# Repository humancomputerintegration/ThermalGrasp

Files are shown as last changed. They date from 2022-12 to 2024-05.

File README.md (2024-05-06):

<p align="center">

![Figure 1 has two photos labelled (a) and (b). Figure 1(a) depicts a user kneeling with their rear knee on artificial turf and their front foot on top of sand. They are wearing thermal feedback devices on their hands and feet, as well as a VR headset. The foot that is in the sand is experiencing cold sensation. One of their hands is holding a wooden dowel rod and is experiencing heat from a fire shown in VR. Figure 1(b) depicts a fabricated device that wraps around the user's hand.](/Images/Fig-01-Large.jpg?raw=true)

</p>

# ThermalGrasp

This is a repository for the prototype ThermalGrasp devices created by Alex Mazursky, Jas Brooks, Beza Desta, and Pedro Lopes at the University of Chicago's [Human Computer Integration Lab](https://lab.plopes.org/). Our wearable thermal interfaces made with the ThermalGrasp approach enable users to grab and walk on real objects with minimal obstruction. For specific study details, please refer to our paper.
## Repository Structure

* `Arduino` contains code for the microcontroller (Arduino Mega).
* `3D-prints` contains models for the form-fitting shells for the hands and feet (.stl files). These can be printed in regular PLA using an FDM 3D printer. Additionally includes Fusion360 assemblies (.f3d files) of the entire device (shells, peltiers, fans, copper, etc.).

## Hardware

<p align="center">

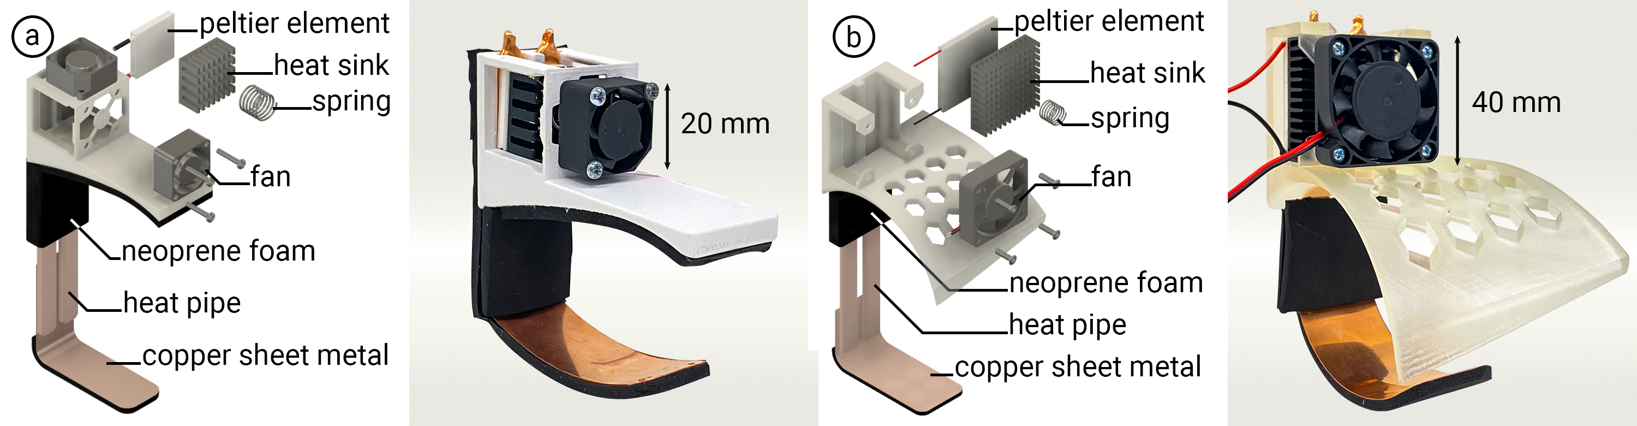
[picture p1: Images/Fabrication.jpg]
Shows our hand and footworn devices. A rendering of the components labeled in an exploded view is depicted, next to an image of the fabricated device.


</p>

Here are the specific hardware components used in each device instantiation and our hardware used in Study 2's backpack.

- Peltiers (foot: TEC12706, hand: CP60231H)
- Copper heat pipes (foot: 70W 11.2 x 3.5 x 100mm, hand: 60W 8.3 x 2.5 x 70mm)
- Copper sheet metal (0.2mm thick)
- Neoprene foam (3.2mm thick, easily compressible)
- Heatsinks (foot: 40 x 40 x 12mm, hand: 20 x 20 x 10mm)
- Fans (foot: 24V, 40 x 40mm, hand: 12V, 20 x 20mm)
- Temperature sensors (100kΩ NTC 3950 thermistors) 
- Motor drivers (VNH3SP30)
- Microcontroller (ATmega2560/Arduino Mega)
- MOSFET (RFP30N06LE, triggers fans)

## Citing

When using or building upon this device in an academic publication, please consider citing as follows:

A. Mazursky, J. Brooks, B. Desta and P. Lopes, "ThermalGrasp: Enabling Thermal Feedback even while Grasping and Walking," in 2024 IEEE Conference Virtual Reality and 3D User Interfaces (VR), Orlando, FL, USA, 2024 pp. 342-353.
doi: 10.1109/VR58804.2024.00056

## Contact

For any questions about this repository, please contact alexmazursky@uchicago.edu

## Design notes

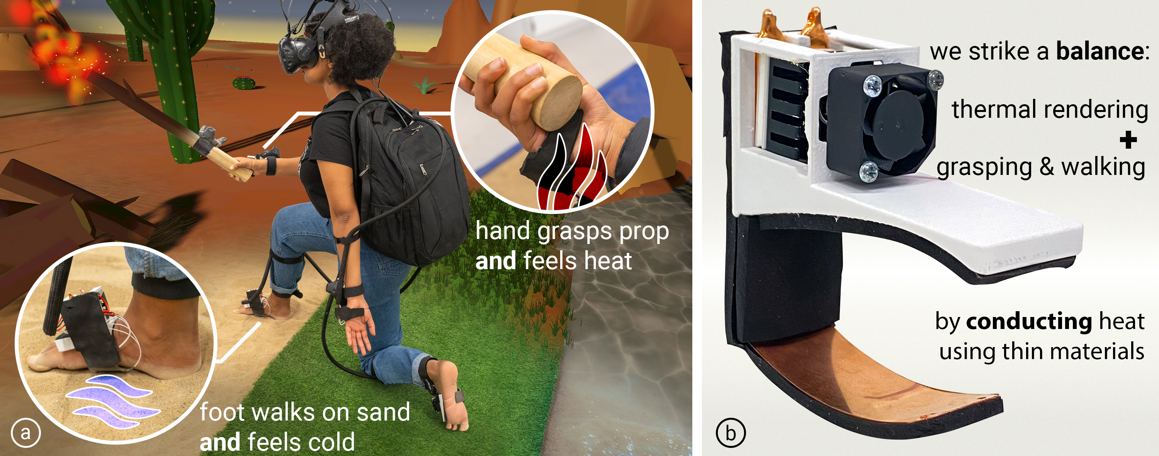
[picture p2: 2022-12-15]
Images/Fig-01-Large.jpg

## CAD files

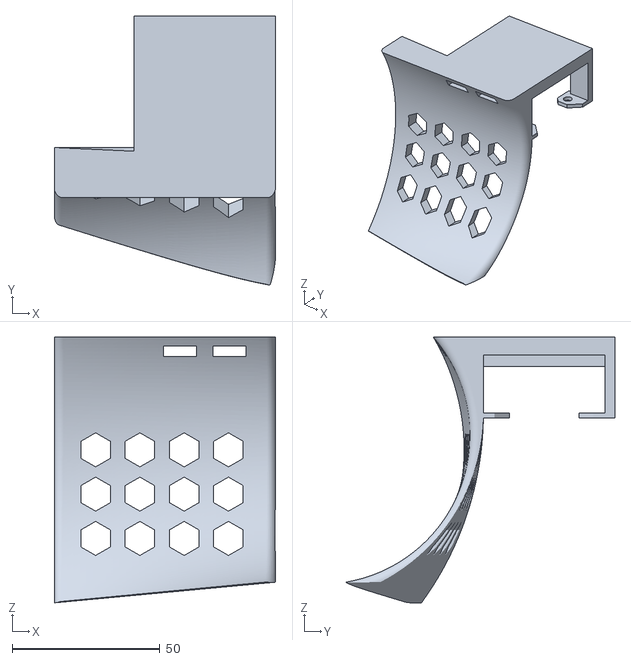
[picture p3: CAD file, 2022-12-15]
3D-prints/shell-foot.stl
75.0 x 91.1 x 90.0

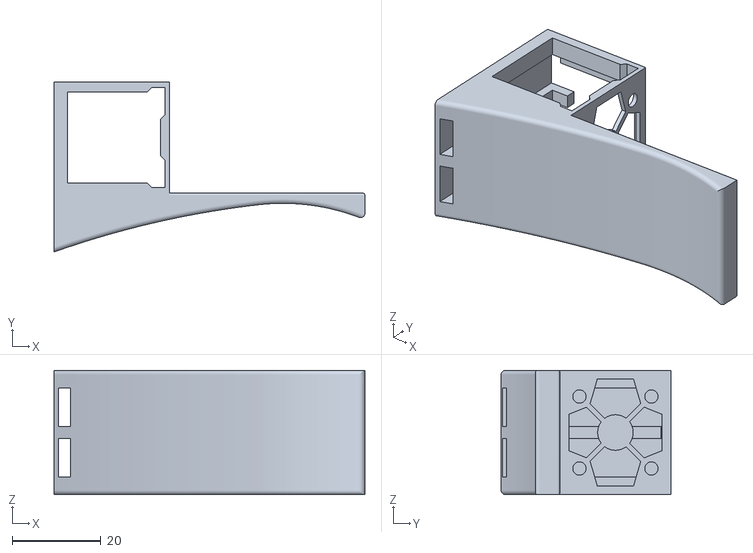
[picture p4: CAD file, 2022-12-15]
3D-prints/shell-hand.stl
70.0 x 38.2 x 28.0

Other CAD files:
3D-prints/ThermalGrasp-hand-assembly.f3d

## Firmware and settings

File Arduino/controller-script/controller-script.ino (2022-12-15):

bool debug = true;

/////////////
// sensing //
/////////////
// which analog pin to connect
#define THERMISTORPIN1 A0
#define THERMISTORPIN2 A1
#define THERMISTORPIN3 A3
#define THERMISTORPIN4 A2 // bug fix due to soldering error
#define THERMISTORPIN5 A4
#define THERMISTORPIN6 A5
#define THERMISTORPIN7 A6
#define THERMISTORPIN8 A7

// resistance at 25 degrees C
#define THERMISTORNOMINAL 100000
// temp. for nominal resistance (almost always 25 C)
#define TEMPERATURENOMINAL 25
// how many samples to take and average, more takes longer
// but is more 'smooth
#define NUMSAMPLES 25
// The beta coefficient of the thermistor (usually 3000-4000)
#define BCOEFFICIENT 3950
// the value of the 'other' resistor
#define SERIESRESISTOR 10000

int samples1[NUMSAMPLES];
int samples2[NUMSAMPLES];
int samples3[NUMSAMPLES];
int samples4[NUMSAMPLES];
int samples5[NUMSAMPLES];
int samples6[NUMSAMPLES];
int samples7[NUMSAMPLES];
int samples8[NUMSAMPLES];

double temp_LH_Peltier;
double temp_LH;
double temp_RH_Peltier;
double temp_RH;
double temp_LF_Peltier;
double temp_LF;
double temp_RF_Peltier;
double temp_RF;

#include <filters.h>
const float cutoff_freq   = 5.0;  //Cutoff frequency in Hz
const float sampling_time = 0.005; //Sampling time in seconds.
IIR::ORDER  order  = IIR::ORDER::OD3; // Order (OD1 to OD4)

// Low-pass filter
Filter f0(cutoff_freq, sampling_time, order);
Filter f1(cutoff_freq, sampling_time, order);
Filter f2(cutoff_freq, sampling_time, order);
Filter f3(cutoff_freq, sampling_time, order);
Filter f4(cutoff_freq, sampling_time, order);
Filter f5(cutoff_freq, sampling_time, order);
Filter f6(cutoff_freq, sampling_time, order);
Filter f7(cutoff_freq, sampling_time, order);

///////////////
// actuation //
///////////////
// left hand
const int LH_inaPin = 25;
const int LH_inbPin = 24;
const int LH_pwmPin = 8;
const int LH_diagaPin = 23;
const int LH_diagbPin = 22;
const int LH_fan = 36;

// right hand
const int RH_inaPin = 29;
const int RH_inbPin = 28;
const int RH_pwmPin = 9;
const int RH_diagaPin = 27;
const int RH_diagbPin = 26;
const int RH_fan = 37;

// left foot
const int LF_inaPin = 33;
const int LF_inbPin = 32;
const int LF_pwmPin = 10;
const int LF_diagaPin = 31;
const int LF_diagbPin = 30;
const int LF_fan = 34;

// right foot
const int RF_inaPin = 4;
const int RF_inbPin = 5;
const int RF_pwmPin = 11;
const int RF_diagaPin = 6;
const int RF_diagbPin = 7;
const int RF_fan = 35;

/////////
// PID //
/////////
#include <AutoPID.h>

double LH_pwm = 0;
double RH_pwm = 0;
double LF_pwm = 0;
double RF_pwm = 0;

double set_temp_LH = 0;
double set_temp_RH = 0;
double set_temp_LF = 0;
double set_temp_RF = 0;

// FEET
// COOLING SETTINGS
#define OUTPUT_MIN_cf -255 // cool
#define OUTPUT_MAX_cf 0 // heat - don't do it
#define KP_cf 200
#define KI_cf 8
#define KD_cf 0
AutoPID PID_RF_c(&temp_RF, &set_temp_RF, &RF_pwm, OUTPUT_MIN_cf, OUTPUT_MAX_cf, KP_cf, KI_cf, KD_cf);
AutoPID PID_LF_c(&temp_LF, &set_temp_LF, &LF_pwm, OUTPUT_MIN_cf, OUTPUT_MAX_cf, KP_cf, KI_cf, KD_cf);
// HEATING SETTINGS
//pid settings and gains
#define OUTPUT_MIN_hf -255 // cool
#define OUTPUT_MAX_hf 255 // heat
#define KP_hf 75
#define KI_hf 3
#define KD_hf 0
AutoPID PID_RF_h(&temp_RF, &set_temp_RF, &RF_pwm, OUTPUT_MIN_hf, OUTPUT_MAX_hf, KP_hf, KI_hf, KD_hf);
AutoPID PID_LF_h(&temp_LF, &set_temp_LF, &LF_pwm, OUTPUT_MIN_hf, OUTPUT_MAX_hf, KP_hf, KI_hf, KD_hf);

// HANDS
// COOLING SETTINGS
#define OUTPUT_MIN_ch -255 // cool
#define OUTPUT_MAX_ch 0 // heat - don't do it
#define KP_ch 30
#define KI_ch 0
#define KD_ch 1
AutoPID PID_RH_c(&temp_RH, &set_temp_RH, &RH_pwm, OUTPUT_MIN_ch, OUTPUT_MAX_ch, KP_ch, KI_ch, KD_ch);
AutoPID PID_LH_c(&temp_LH, &set_temp_LH, &LH_pwm, OUTPUT_MIN_ch, OUTPUT_MAX_ch, KP_ch, KI_ch, KD_ch);
// HEATING SETTINGS
//pid settings and gains
#define OUTPUT_MIN_hh -10 // cool
#define OUTPUT_MAX_hh 255 // heat
#define KP_hh 15
#define KI_hh 0.1
#define KD_hh 0.5
AutoPID PID_RH_h(&temp_RH, &set_temp_RH, &RH_pwm, OUTPUT_MIN_hh, OUTPUT_MAX_hh, KP_hh, KI_hh, KD_hh);
AutoPID PID_LH_h(&temp_LH, &set_temp_LH, &LH_pwm, OUTPUT_MIN_hh, OUTPUT_MAX_hh, KP_hh, KI_hh, KD_hh);

// Serial comms
const byte numChars = 32;
char receivedChars[numChars];
char tempChars[numChars];        // temporary array for use when parsing
boolean newData = false;
int printCounter = 0;

//============

void setup() {
  Serial.begin(115200);
  analogReference(EXTERNAL);

  // setup left hand
  pinMode(LH_inaPin, OUTPUT);
  pinMode(LH_inbPin, OUTPUT);
  pinMode(LH_pwmPin, OUTPUT);
  pinMode(LH_diagaPin, INPUT);
  pinMode(LH_diagbPin, INPUT);
  pinMode(LH_fan, OUTPUT);

  // setup right hand
  pinMode(RH_inaPin, OUTPUT);
  pinMode(RH_inbPin, OUTPUT);
  pinMode(RH_pwmPin, OUTPUT);
  pinMode(RH_diagaPin, INPUT);
  pinMode(RH_diagbPin, INPUT);
  pinMode(RH_fan, OUTPUT);

  // setup left foot
  pinMode(LF_inaPin, OUTPUT);
  pinMode(LF_inbPin, OUTPUT);
  pinMode(LF_pwmPin, OUTPUT);
  pinMode(LF_diagaPin, INPUT);
  pinMode(LF_diagbPin, INPUT);
  pinMode(LF_fan, OUTPUT);

  // setup right foot
  pinMode(RF_inaPin, OUTPUT);
  pinMode(RF_inbPin, OUTPUT);
  pinMode(RF_pwmPin, OUTPUT);
  pinMode(RF_diagaPin, INPUT);
  pinMode(RF_diagbPin, INPUT);
  pinMode(RF_fan, OUTPUT);

  //if temperature is more than X degrees below or above setpoint, OUTPUT will be set to min or max respectively
  PID_RH_c.setBangBang(20);
  PID_RH_h.setBangBang(10);
  PID_LH_c.setBangBang(20);
  PID_LH_h.setBangBang(10);
  PID_RF_c.setBangBang(1);
  PID_RF_h.setBangBang(2);
  PID_LF_c.setBangBang(1);
  PID_LF_h.setBangBang(2);

  //set PID update interval
  PID_RH_c.setTimeStep(10);
  PID_RH_h.setTimeStep(10);
  PID_LH_c.setTimeStep(10);
  PID_LH_h.setTimeStep(10);
  PID_RF_c.setTimeStep(10);
  PID_RF_h.setTimeStep(10);
  PID_LF_c.setTimeStep(10);
  PID_LF_h.setTimeStep(10);
  //Serial.println("Enter data in this style <70, 0, -120, -255>  ");
}

//============

void loop() {
  recvWithStartEndMarkers();
  if (newData == true) {
    strcpy(tempChars, receivedChars);
    // this temporary copy is necessary to protect the original data
    //   because strtok() used in parseData() replaces the commas with \0
    parseData();
    if(debug == true) {
      showParsedData();
    }
    newData = false;
  }

  // pull the sensor readings
  getSensorData();

  // then heat/cool each hand/foot accordingly
  if (set_temp_LH == 0) { // kill the motor driver
    LH_pwm = 0;
  }
  else if (set_temp_LH <= 30) {
    PID_LH_c.run(); //call every loop, updates automatically at certain time interval
  }
  else if (set_temp_LH > 30)  {
    PID_LH_h.run(); //call every loop, updates automatically at certain time interval
  }

  if (set_temp_RH == 0) { // kill the motor driver
    RH_pwm = 0;
  }
  else if (set_temp_RH <= 30) {
    PID_RH_c.run(); //call every loop, updates automatically at certain time interval
  }
  else if (set_temp_RH > 30)  {
    PID_RH_h.run(); //call every loop, updates automatically at certain time interval
  }

  if (set_temp_LF == 0) { // kill the motor driver
    LF_pwm = 0;
  }
  else if (set_temp_LF <= 28) {
    PID_LF_c.run(); //call every loop, updates automatically at certain time interval
  }
  else if (set_temp_LF > 28)  {
    PID_LF_h.run(); //call every loop, updates automatically at certain time interval
  }

  if (set_temp_RF == 0) { // kill the motor driver
    RF_pwm = 0;
  }
  else if (set_temp_RF <= 28) {
    PID_RF_c.run(); //call every loop, updates automatically at certain time interval
  }
  else if (set_temp_RF > 28)  {
    PID_RF_h.run(); //call every loop, updates automatically at certain time interval
  }

  runThermals();

  printCounter++;
  if (debug == true && printCounter > 50) {
    if (set_temp_RF <= 28) {
      //Serial.print("---RF: Cooling---   ");
    }
    else if (set_temp_RF > 28) {
      //Serial.print("---RF: Heating---   ");
    }
    Serial.print("LH set temp: ");
    Serial.print(set_temp_LH);
    Serial.print(", LH PWM: ");
    Serial.print(LH_pwm);
    Serial.print(", RH set temp: ");
    Serial.print(set_temp_RH);
    Serial.print(", RH PWM: ");
    Serial.print(RH_pwm);
    Serial.print(", LF set temp: ");
    Serial.print(set_temp_LF);
    Serial.print(", LF PWM: ");
    Serial.print(LF_pwm);
    Serial.print(", RF set temp: ");
    Serial.print(set_temp_RF);
    Serial.print(", RF PWM: ");
    Serial.println(RF_pwm);

    Serial.print("temp_LH_Peltier: ");
    Serial.print(temp_LH_Peltier);
    Serial.print(", temp_LH: ");
    Serial.print(temp_LH);
    Serial.print(", temp_RH_Peltier: ");
    Serial.print(temp_RH_Peltier);
    Serial.print(", temp_RH: ");
    Serial.print(temp_RH);
    Serial.print(", temp_LF_Peltier: ");
    Serial.print(temp_LF_Peltier);
    Serial.print(", temp_LF: ");
    Serial.print(temp_LF);
    Serial.print(", temp_RF_Peltier: ");
    Serial.print(temp_RF_Peltier);
    Serial.print(", temp_RF: ");
    Serial.println(temp_RF);

    printCounter = 0;
  }
}

//============

void getSensorData() {
  uint8_t i;
  float average1;
  float average2;
  float average3;
  float average4;
  float average5;
  float average6;
  float average7;
  float average8;

  // take N samples in a row
  for (i = 0; i < NUMSAMPLES; i++) {
    samples1[i] = analogRead(THERMISTORPIN1);
    samples2[i] = analogRead(THERMISTORPIN2);
    samples3[i] = analogRead(THERMISTORPIN3);
    samples4[i] = analogRead(THERMISTORPIN4);
    samples5[i] = analogRead(THERMISTORPIN5);
    samples6[i] = analogRead(THERMISTORPIN6);
    samples7[i] = analogRead(THERMISTORPIN7);
    samples8[i] = analogRead(THERMISTORPIN8);
  }

  // average all the samples out
  average1 = 0;
  average2 = 0;
  average3 = 0;
  average4 = 0;
  average5 = 0;
  average6 = 0;
  average7 = 0;
  average8 = 0;
  for (i = 0; i < NUMSAMPLES; i++) {
    average1 += samples1[i];
    average2 += samples2[i];
    average3 += samples3[i];
    average4 += samples4[i];
    average5 += samples5[i];
    average6 += samples6[i];
    average7 += samples7[i];
    average8 += samples8[i];
  }
  average1 /= NUMSAMPLES;
  average2 /= NUMSAMPLES;
  average3 /= NUMSAMPLES;
  average4 /= NUMSAMPLES;
  average5 /= NUMSAMPLES;
  average6 /= NUMSAMPLES;
  average7 /= NUMSAMPLES;
  average8 /= NUMSAMPLES;

  // convert the value to resistance, then to temperature
  average1 = 1023 / average1 - 1;
  average1 = SERIESRESISTOR / average1;
  float steinhart1;
  steinhart1 = average1 / THERMISTORNOMINAL;     // (R/Ro)
  steinhart1 = log(steinhart1);                  // ln(R/Ro)
  steinhart1 /= BCOEFFICIENT;                   // 1/B * ln(R/Ro)
  steinhart1 += 1.0 / (TEMPERATURENOMINAL + 273.15); // + (1/To)
  steinhart1 = 1.0 / steinhart1;                 // Invert
  steinhart1 -= 273.15;                         // convert absolute temp to C

  average2 = 1023 / average2 - 1;
  average2 = SERIESRESISTOR / average2;
  float steinhart2;
  steinhart2 = average2 / THERMISTORNOMINAL;     // (R/Ro)
  steinhart2 = log(steinhart2);                  // ln(R/Ro)
  steinhart2 /= BCOEFFICIENT;                   // 1/B * ln(R/Ro)
  steinhart2 += 1.0 / (TEMPERATURENOMINAL + 273.15); // + (1/To)
  steinhart2 = 1.0 / steinhart2;                 // Invert
  steinhart2 -= 273.15;                         // convert absolute temp to C

  average3 = 1023 / average3 - 1;
  average3 = SERIESRESISTOR / average3;
  float steinhart3;
  steinhart3 = average3 / THERMISTORNOMINAL;     // (R/Ro)
  steinhart3 = log(steinhart3);                  // ln(R/Ro)
  steinhart3 /= BCOEFFICIENT;                   // 1/B * ln(R/Ro)
  steinhart3 += 1.0 / (TEMPERATURENOMINAL + 273.15); // + (1/To)
  steinhart3 = 1.0 / steinhart3;                 // Invert
  steinhart3 -= 273.15;                         // convert absolute temp to C

  average4 = 1023 / average4 - 1;
  average4 = SERIESRESISTOR / average4;
  float steinhart4;
  steinhart4 = average4 / THERMISTORNOMINAL;     // (R/Ro)
  steinhart4 = log(steinhart4);                  // ln(R/Ro)
  steinhart4 /= BCOEFFICIENT;                   // 1/B * ln(R/Ro)
  steinhart4 += 1.0 / (TEMPERATURENOMINAL + 273.15); // + (1/To)
  steinhart4 = 1.0 / steinhart4;                 // Invert
  steinhart4 -= 273.15;                         // convert absolute temp to C

  average5 = 1023 / average5 - 1;
  average5 = SERIESRESISTOR / average5;
  float steinhart5;
  steinhart5 = average5 / THERMISTORNOMINAL;     // (R/Ro)
  steinhart5 = log(steinhart5);                  // ln(R/Ro)
  steinhart5 /= BCOEFFICIENT;                   // 1/B * ln(R/Ro)
  steinhart5 += 1.0 / (TEMPERATURENOMINAL + 273.15); // + (1/To)
  steinhart5 = 1.0 / steinhart5;                 // Invert
  steinhart5 -= 273.15;                         // convert absolute temp to C

  average6 = 1023 / average6 - 1;
  average6 = SERIESRESISTOR / average6;
  float steinhart6;
  steinhart6 = average6 / THERMISTORNOMINAL;     // (R/Ro)
  steinhart6 = log(steinhart6);                  // ln(R/Ro)
  steinhart6 /= BCOEFFICIENT;                   // 1/B * ln(R/Ro)
  steinhart6 += 1.0 / (TEMPERATURENOMINAL + 273.15); // + (1/To)
  steinhart6 = 1.0 / steinhart6;                 // Invert
  steinhart6 -= 273.15;                         // convert absolute temp to C

  average7 = 1023 / average7 - 1;
  average7 = SERIESRESISTOR / average7;
  float steinhart7;
  steinhart7 = average7 / THERMISTORNOMINAL;     // (R/Ro)
  steinhart7 = log(steinhart7);                  // ln(R/Ro)
  steinhart7 /= BCOEFFICIENT;                   // 1/B * ln(R/Ro)
  steinhart7 += 1.0 / (TEMPERATURENOMINAL + 273.15); // + (1/To)
  steinhart7 = 1.0 / steinhart7;                 // Invert
  steinhart7 -= 273.15;                         // convert absolute temp to C

  average8 = 1023 / average8 - 1;
  average8 = SERIESRESISTOR / average8;
  float steinhart8;
  steinhart8 = average8 / THERMISTORNOMINAL;     // (R/Ro)
  steinhart8 = log(steinhart8);                  // ln(R/Ro)
  steinhart8 /= BCOEFFICIENT;                   // 1/B * ln(R/Ro)
  steinhart8 += 1.0 / (TEMPERATURENOMINAL + 273.15); // + (1/To)
  steinhart8 = 1.0 / steinhart8;                 // Invert
  steinhart8 -= 273.15;                         // convert absolute temp to C

  temp_LH_Peltier = f0.filterIn(steinhart1);
  temp_LH = f1.filterIn(steinhart2);
  temp_RH_Peltier = f2.filterIn(steinhart3);
  temp_RH = f3.filterIn(steinhart4);
  temp_LF_Peltier = f4.filterIn(steinhart5);
  temp_LF = f5.filterIn(steinhart6);
  temp_RF_Peltier = f6.filterIn(steinhart7);
  temp_RF = f7.filterIn(steinhart8);
}

//============

void runThermals() {
  // Left hand
  if (LH_pwm >= 0) {
    digitalWrite(LH_inaPin, HIGH);
    digitalWrite(LH_inbPin, LOW);
    analogWrite(LH_pwmPin, LH_pwm);
  }
  else  {
    digitalWrite(LH_inaPin, LOW);
    digitalWrite(LH_inbPin, HIGH);
    analogWrite(LH_pwmPin, abs(LH_pwm));
  }

  if (set_temp_LH == 0) {
    digitalWrite(LH_fan, LOW);
  }
  else if (temp_LH >= set_temp_LH) {
    digitalWrite(LH_fan, HIGH);
  }
  else {
    digitalWrite(LH_fan, LOW);
  }

  // Right hand
  if (RH_pwm >= 0) {
    digitalWrite(RH_inaPin, HIGH);
    digitalWrite(RH_inbPin, LOW);
    analogWrite(RH_pwmPin, RH_pwm);
  }
  else  {
    digitalWrite(RH_inaPin, LOW);
    digitalWrite(RH_inbPin, HIGH);
    analogWrite(RH_pwmPin, abs(RH_pwm));
  }

  if (set_temp_RH == 0) {
    digitalWrite(RH_fan, LOW);
  }
  else if (temp_RH >= set_temp_RH) {
    digitalWrite(RH_fan, HIGH);
  }
  else {
    digitalWrite(RH_fan, LOW);
  }

  // Left foot
  if (LF_pwm >= 0) {
    digitalWrite(LF_inaPin, HIGH);
    digitalWrite(LF_inbPin, LOW);
    analogWrite(LF_pwmPin, LF_pwm);
  }
  else  {
    digitalWrite(LF_inaPin, LOW);
    digitalWrite(LF_inbPin, HIGH);
    analogWrite(LF_pwmPin, abs(LF_pwm));
  }

  if (temp_LF >= set_temp_LF) {
    digitalWrite(LF_fan, HIGH);
  }
  else {
    digitalWrite(LF_fan, LOW);
  }

  // Right foot
  if (RF_pwm >= 0) {
    digitalWrite(RF_inaPin, HIGH);
    digitalWrite(RF_inbPin, LOW);
    analogWrite(RF_pwmPin, RF_pwm);
    digitalWrite(RF_fan, LOW);
  }
  else  {
    digitalWrite(RF_inaPin, LOW);
    digitalWrite(RF_inbPin, HIGH);
    analogWrite(RF_pwmPin, abs(RF_pwm));
    digitalWrite(RF_fan, HIGH);
  }

  if (temp_RF >= set_temp_RF) {
    digitalWrite(RF_fan, HIGH);
  }
  else {
    digitalWrite(RF_fan, LOW);
  }
  
}

//============

void recvWithStartEndMarkers() {
  static boolean recvInProgress = false;
  static byte ndx = 0;
  char startMarker = '<';
  char endMarker = '>';
  char rc;

  while (Serial.available() > 0 && newData == false) {
    rc = Serial.read();

    if (recvInProgress == true) {
      if (rc != endMarker) {
        receivedChars[ndx] = rc;
        ndx++;
        if (ndx >= numChars) {
          ndx = numChars - 1;
        }
      }
      else {
        receivedChars[ndx] = '\0'; // terminate the string
        recvInProgress = false;
        ndx = 0;
        newData = true;
      }
    }

    else if (rc == startMarker) {
      recvInProgress = true;
    }
  }
}

//============

void parseData() {      // split the data into its parts

  char * strtokIndx; // this is used by strtok() as an index

  //strtokIndx = strtok(tempChars,",");      // get the first part - the string
  //strcpy(messageFromPC, strtokIndx); // copy it to messageFromPC

  strtokIndx = strtok(tempChars, ",");     // get the first part - the string
  set_temp_LH = atoi(strtokIndx); // copy it to messageFromPC

  strtokIndx = strtok(NULL, ","); // this continues where the previous call left off
  set_temp_RH = atoi(strtokIndx);     // convert this part to an integer

  strtokIndx = strtok(NULL, ",");     // get the first part - the string
  set_temp_LF = atoi(strtokIndx); // copy it to messageFromPC

  strtokIndx = strtok(NULL, ","); // this continues where the previous call left off
  set_temp_RF = atoi(strtokIndx);     // convert this part to an integer

  //strtokIndx = strtok(NULL, ",");
  //floatFromPC = atof(strtokIndx);     // convert this part to a float

}

//============

void showParsedData() {
  Serial.print("set_temp_LH ");
  Serial.println(set_temp_LH);
  Serial.print("set_temp_RH ");
  Serial.println(set_temp_RH);
  Serial.print("set_temp_LF ");
  Serial.println(set_temp_LF);
  Serial.print("set_temp_RF ");
  Serial.println(set_temp_RF);
}

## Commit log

2022-12-15 Added arduino firmware and updated README
2022-12-15 added 3D print files, updated README
    [ThermalGrasp-hand-assembly.f3d, shell-foot.stl, shell-hand.stl]
2022-12-15 devices images added.
